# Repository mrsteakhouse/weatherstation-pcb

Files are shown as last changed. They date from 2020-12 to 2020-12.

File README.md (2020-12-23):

# Weather station PCB Schematics 

These are the PCB schematics for the weatherstation project.
It is designed to work with an ESP-01 tuned for deep sleep.
The circuit is powered by any 9V power source (6xAA works best).
A linear voltage regulator ([MCP1755S](http://ww1.microchip.com/downloads/en/devicedoc/25160a.pdf)) breaks that 9V down to 3.3V.
The MCU communicates through I2C with the on board voltage sensor ([MCP3421](https://www.microchip.com/wwwproducts/en/en520011)) and an air quality sensor like the [BME-280](https://www.bosch-sensortec.com/products/environmental-sensors/humidity-sensors-bme280/).
Additionaly any other I2C device that runs on 3.3V may be connected through an extra pair of VCC, GND, SCL and SDA.

The implementation can be found [here](https://github.com/mrsteakhouse/weatherstation/tree/main).

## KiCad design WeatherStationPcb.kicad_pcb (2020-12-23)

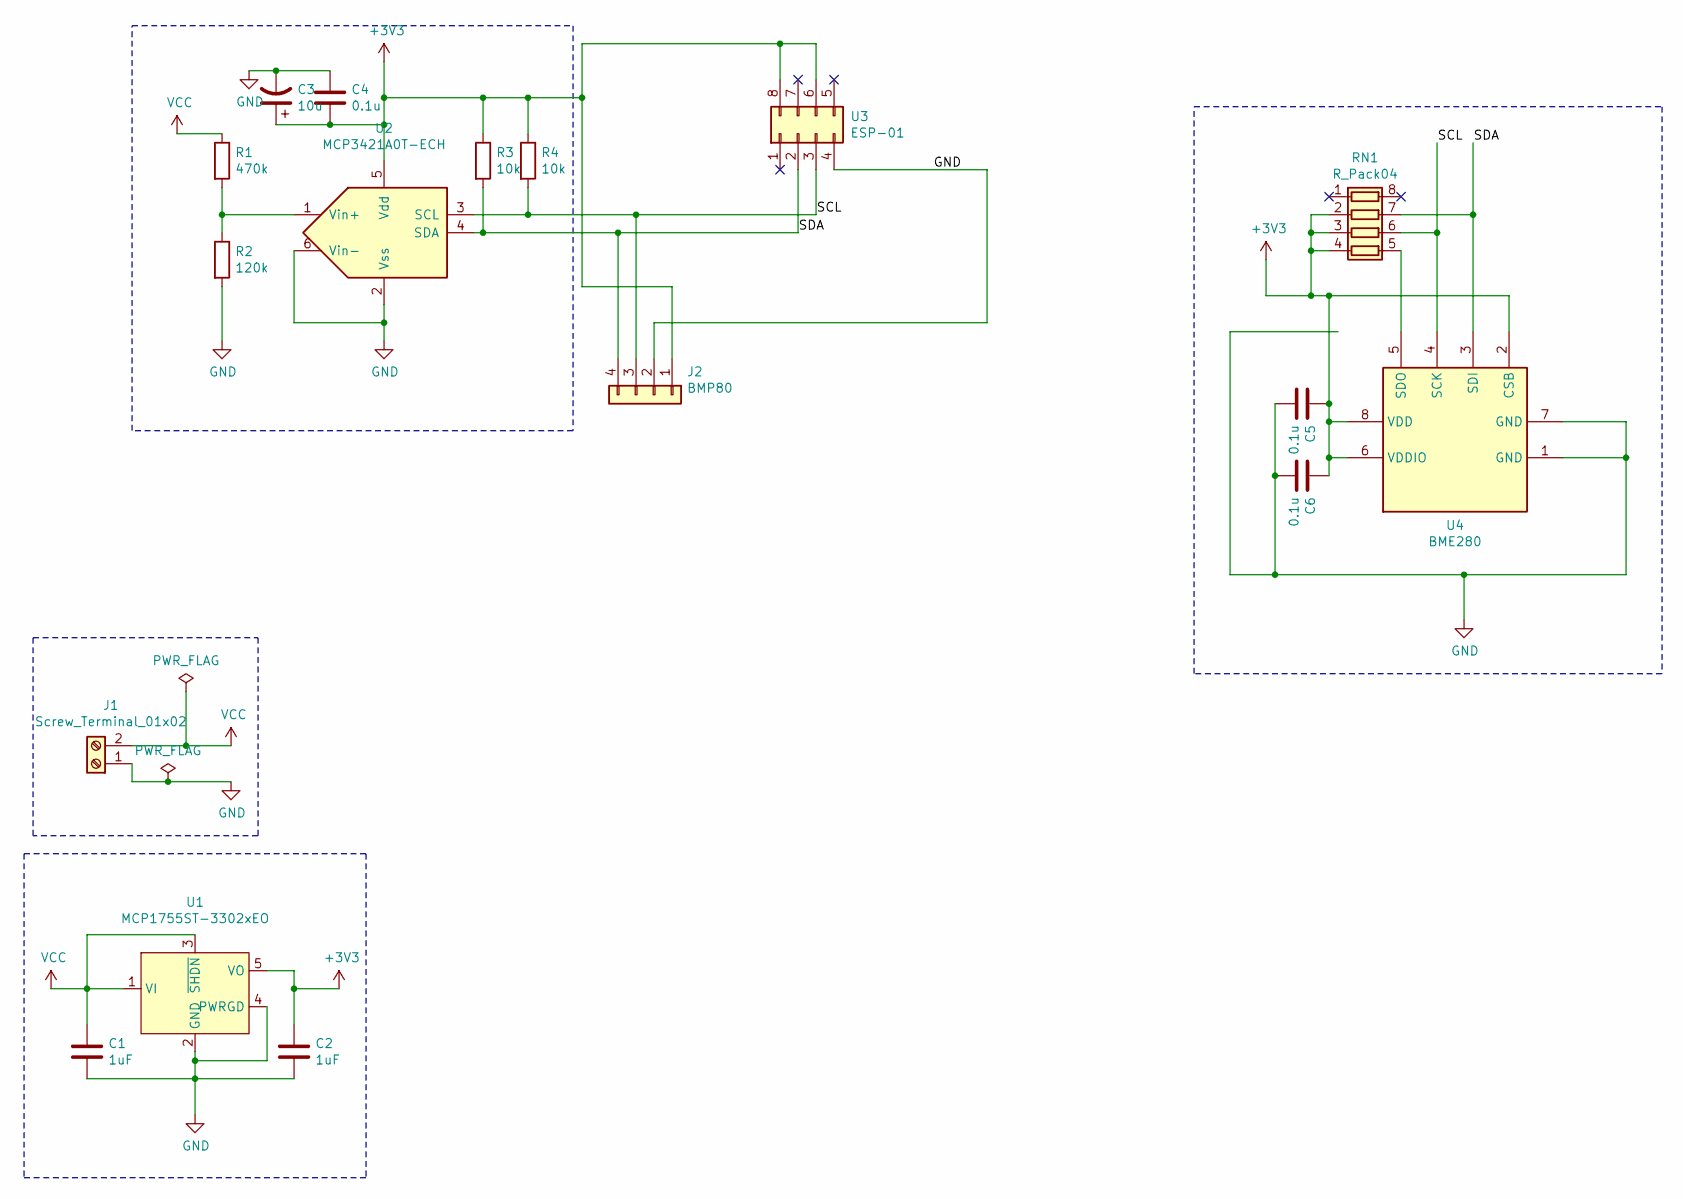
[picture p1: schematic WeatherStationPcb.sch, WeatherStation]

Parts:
C1, C2: 1uF; C_0805_2012Metric
C3: 10u; CP_EIA-6032-28_Kemet-C
C4, C5, C6: 0.1u; C_0805_2012Metric
J1: Screw_Terminal_01x02; TerminalBlock_bornier-2_P5.08mm
J2: BMP80; PinSocket_1x04_P2.54mm_Vertical
R1: 470k; R_0805_2012Metric
R2: 120k; R_0805_2012Metric
R3, R4: 10k; R_0805_2012Metric
RN1: R_Pack04; R_Array_Convex_4x0603
U1: MCP1755ST-3302xEO; SOT-23-5
U2: MCP3421A0T-ECH; SOT-23-6
U3: ESP-01
U4: BME280; Bosch_LGA-8_2.5x2.5mm_P0.65mm_ClockwisePinNumbering

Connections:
+3V3: C2.1, C3.1, C4.1, C5.2, C6.2, J2.1, R3.1, R4.1, RN1.2 (R2.1), RN1.3 (R3.1), RN1.4 (R4.1), U1.5 (VO), U2.5 (Vdd), U3.6 (CH_PD), U3.8 (VCC), U4.2 (CSB), U4.6 (VDDIO), U4.8 (VDD)
/SCL: J2.3, R4.2, RN1.6 (R3.2), U2.3 (SCL), U3.3 (GPIO2), U4.4 (SCK)
/SDA: J2.4, R3.2, RN1.7 (R2.2), U2.4 (SDA), U3.2 (GPIO0), U4.3 (SDI)
GND: C1.2, C2.2, C3.2, C4.2, C5.1, C6.1, J1.1, J2.2, R2.2, U1.2 (GND), U1.4 (PWRGD), U2.2 (Vss), U2.6 (Vin-), U3.4 (GND), U4.1 (GND), U4.7 (GND)
unnamed: R1.2, R2.1, U2.1 (Vin+)
unnamed: RN1.5 (R4.2), U4.5 (SDO)
VCC: C1.1, J1.2, R1.1, U1.1 (VI), U1.3 (~SHDN)

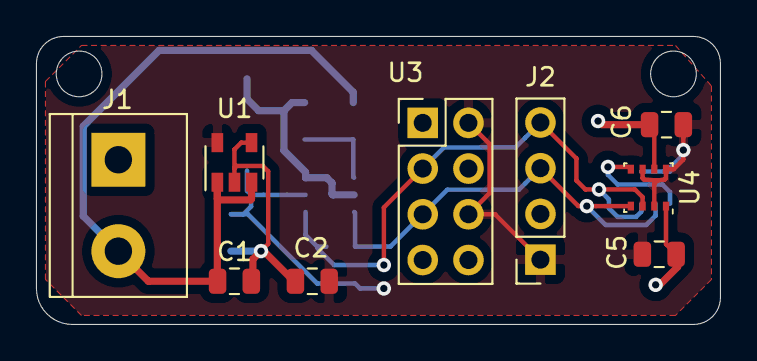
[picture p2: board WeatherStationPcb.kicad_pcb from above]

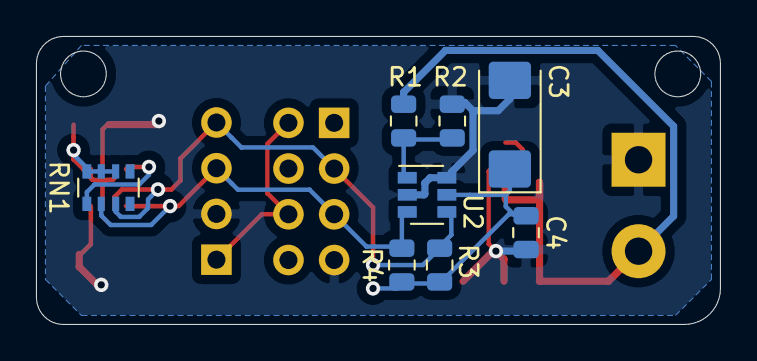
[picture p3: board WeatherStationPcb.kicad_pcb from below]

Board: 2 copper layers, 38.0 x 16.0 mm, 17 parts (8 on the bottom side), 7 nets.
